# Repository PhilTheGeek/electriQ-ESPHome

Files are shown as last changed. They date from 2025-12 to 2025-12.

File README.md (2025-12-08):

# electriQ-ESPHome

## Background

I bought a number of these electriQ minisplit air conditioners and they work fine with the in-built wifi module and its Tuya integration into Home Assistant.  But I prefer to use on-premises solutions that don't rely on cloud, especially when that cloud is Chinese owned. A bit of reverse engineering of the Tuya datapoints led to this design.

The electriQ brand is, as far as I can tell, a UK specific brand that is put onto more generic Chinese products.  If your board looks like these then it might also work.

Front of the original board:
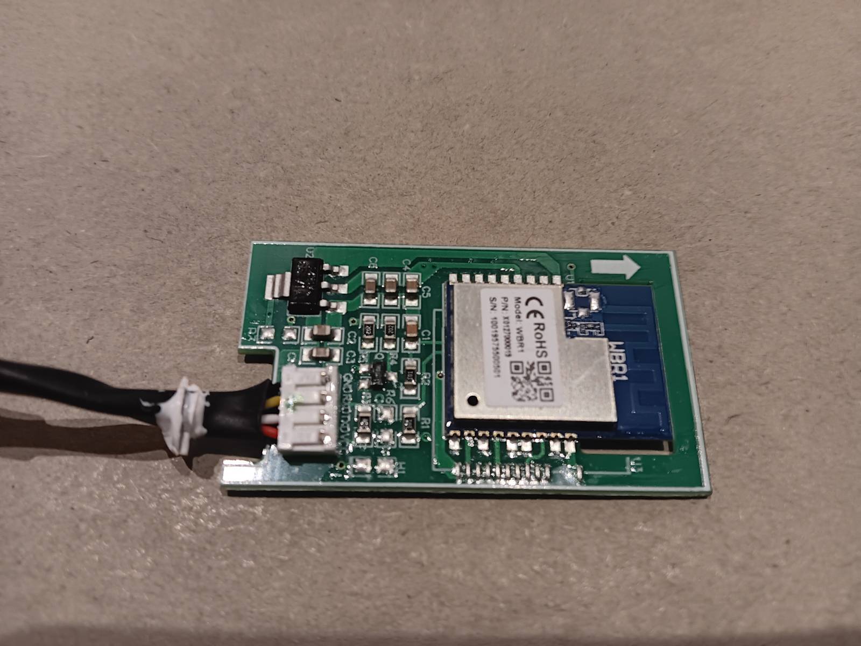
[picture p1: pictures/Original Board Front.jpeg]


Back of the original board:
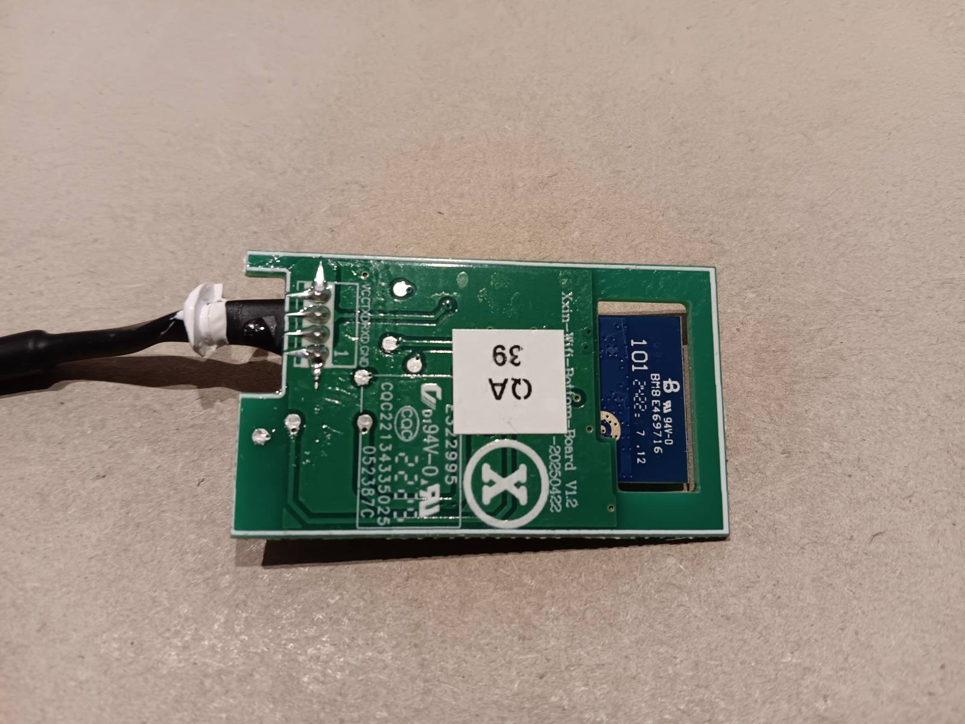
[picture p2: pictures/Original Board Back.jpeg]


## Bill of Materials

| Part | Part Number |
| ---- | --- |
| R1 | 10k 0603 |
| R2 | 10k 0603 |
| R3 | 100R 0603 |
| R4 | 10k 0603 |
| R5 | 10k 0603 |
| R6 | 100R 0603 |
| U1 | ESP32-C3 SuperMini (must be one with onboard flash)|
| J1 | S4B-PH-K-S |

## ESPHome

Use the example YAML, amending entries with {} tags.  If your unit has horizontal swing then uncomment the 107 datapoint.  
There are 3 bitmask bytes which I've left in. I've never seen them change. Data point 108 is always 0xFF, 109 0x00 and 110 0x00.  Please let me know if you find out if they change and why.  

## New board

Gerbers in the gerber folder and the board will end up looking a bit like this (I've rotated Q2 and R4 to align with the other components since building this board). I added the JST connector for ease but the solder header could be transferred from the original board.

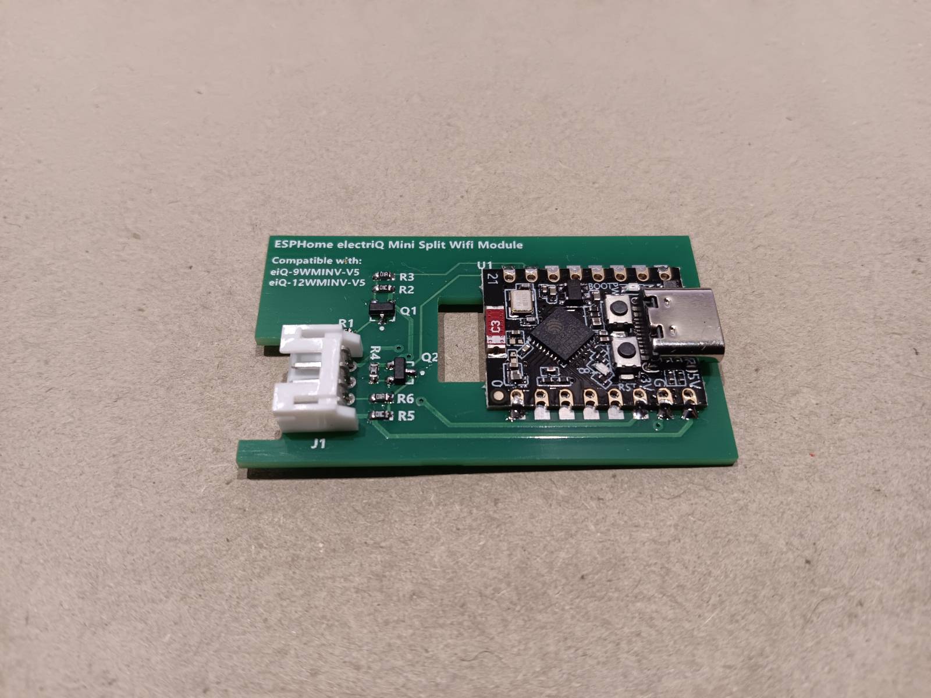
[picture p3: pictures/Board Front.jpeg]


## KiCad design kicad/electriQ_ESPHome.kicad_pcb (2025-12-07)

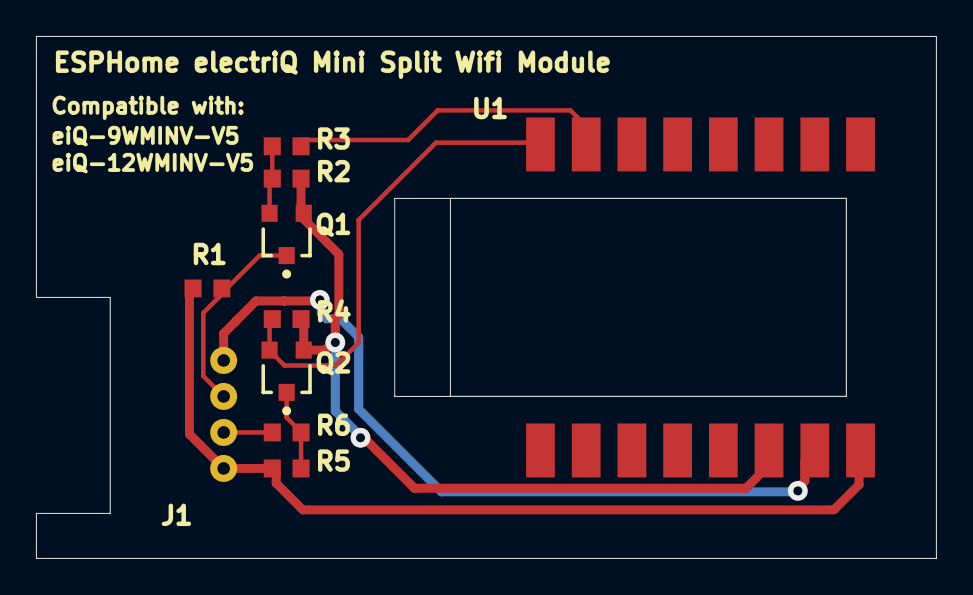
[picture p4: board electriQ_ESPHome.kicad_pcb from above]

Board: 2 copper layers, 50.0 x 29.0 mm, 10 parts (0 on the bottom side), 9 nets.

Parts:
J1: S4B-PH-K-S; s4b-ph-k-s
Q1, Q2: BSS138; SOT23
R1, R2, R4, R5: 10k; ERA-0603
R3, R6: 100R; ERA-0603
U1: ESP32-C3 SuperMini

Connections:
+5: J1.4, R1.2, R5.2, U1.16
GND: J1.1, U1.15
NetQ1_2: Q1.2, R2.1, R3.1
NetQ2_1: Q2.1, R5.1, R6.2
RXD: J1.2, Q1.1, R1.1
RXD_3V3: R3.2, U1.7
TXD: J1.3, R6.1
TXD_3V3: Q2.2, R4.1, U1.8
VCC: Q1.3, Q2.3, R2.2, R4.2, U1.14

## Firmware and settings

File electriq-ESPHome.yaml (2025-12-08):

substitutions:

###############################
# Location/Site Details:
#
   # The site location, upon which this device is deployed. Used to populate a Text Sensor with this information.
  site: ""
   # Allows ESP device to be automatically lined to an 'Area' in Home Assistant. Typically used for areas such as 'Lounge Room', 'Kitchen' etc  
  location: ""
   # The phase in the home power supply, upon which this device is utilsed. 1p = A. 3p = A, B or C.  (myHome GPO 1 = Phase C, GPO 2 = Phase A, GPO 3 = Phase B)  
  power_circuit: "1p"  

  project_name: "electriQ eIQ-12WMINV v5"
  project_version: "1.1"
  
###############################
# Time Update Settings:
#
   # Set timezone of the smart plug. Useful if the aircon is in a location different to the HA server. Can be entered in unix Country/Area format (i.e. "Australia/Sydney")
  timezone: "Europe/London"
   # Set the duration between the sntp service polling ntp.org servers for an update
  sntp_update_interval: 4h
   # Network time servers for your region, enter from lowest to highest priority
  sntp_server_1: "0.uk.pool.ntp.org"
  sntp_server_2: "1.uk.pool.ntp.org"
  sntp_server_3: "2.uk.pool.ntp.org"

 ###############################
# Network Settings
#
   # Enable or disable the use of IPv6 networking on the device
  ipv6_enable: "false"

##########################
# Device Settings:
#  
   # Set the update interval for sensors  
  sensor_update_interval: 10s   
   # Define logging level: NONE, ERROR, WARN, INFO, DEBUG (Default), VERBOSE, VERY_VERBOSE
  log_level: "DEBUG"

esphome:
  name: electriq-aircon
  friendly_name: electriq-aircon

esp32:
  board: esp32-c3-devkitm-1
  framework:
    type: esp-idf

# Enable logging
logger:

# Enable Home Assistant API
api:
  encryption:
    # replace {APIKEY} with your HA API key
    key: {APIKEY}

ota:
  - platform: esphome
    # replace {OTA_PASSWORD} with esphome OTA password
    password: {OTA_PASSWORD}

wifi:
  ssid: !secret wifi_ssid
  password: !secret wifi_password
  min_auth_mode: wpa2

  # Enable fallback hotspot (captive portal) in case wifi connection fails
  ap:
    # replace {AP_SSID} and {AP_PASSWORD} with ssid and password to be used with captive portal
    ssid: {AP_SSID}
    password: {AP_PASSWORD}

captive_portal:

   # Enable local webserver on ESP Device
web_server:
   # TCP Port the webserver operates upon
  port: 80
   # Webserver version (default is 2).
  version: 3
  
##########################################################################
#
# Buttons - To trigger actions, such as reboot, reset
#

button:
  - platform: restart
    name: 'Restart Device'
    entity_category: config
    web_server:
      sorting_weight: 45

  - platform: safe_mode
    name: "Safe Mode"
    internal: false
    entity_category: config
    web_server:
      sorting_weight: 46

  - platform: factory_reset
    name: Reset - Factory Default
    id: Reset
    entity_category: config
    web_server:
      sorting_weight: 47

##########################################################################
#
# Text Sensors
#

text_sensor:

  # Creates a sensor showing when the device was last restarted
  - platform: template
    name: 'Device Last Restart'
    id: device_last_restart
    icon: mdi:clock
    entity_category: diagnostic
    web_server:
      sorting_weight: 37

  #  Creates a sensor showing power circuit / phase of the device
  - platform: template
    name: 'Power Circuit'
    id: power_circuit
    icon: "mdi:electric-switch"
    entity_category: diagnostic
    lambda: |-
      return {"${power_circuit}"};
#    update_interval: 1h
    web_server:
      sorting_weight: 38

   # Creates a sensor of the name of installed project
  - platform: template
    name: 'Project Name'
    id: project_name
    icon: "mdi:label-outline"
    entity_category: diagnostic
    lambda: |-
      return {"${project_name}"};
#    update_interval: 1h
    web_server:
      sorting_weight: 39

   # Creates a sensor of the version of installed project
  - platform: template
    name: 'Project Version'
    id: project_version
    icon: "mdi:label-outline"
    entity_category: diagnostic
    lambda: |-
      return {"${project_version}"};
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
